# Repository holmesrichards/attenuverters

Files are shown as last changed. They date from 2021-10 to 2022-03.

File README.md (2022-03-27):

# Attenuverters

This is a utility synthesizer module in Kosmo format. It provides three attenuverters — that is, on each of the Out 1/2/3 outputs is whatever voltage went into In 1/2/3 with buffering and attenuation and, if the attenuator slider is below the midpoint, inverted as well. 

A toggle switch allows replacing In 1 with a 10 volt reference, allowing you to get any DC voltage from -10 V to +10 V on Out 1.

The sum of the three outputs appears on the Sum Out jack, and the inverted sum on the inverted Sum Out jack.

The attenuverters' response to the slider position is nonlinear: it is steeper on the ends than in the middle, making it easier to set small values precisely.

The design is inspired and informed by the Kassutronics Attenuverter/Mixer Eurorack module.

## Current draw
11 mA +12 V, 10 mA -12 V

## Photos

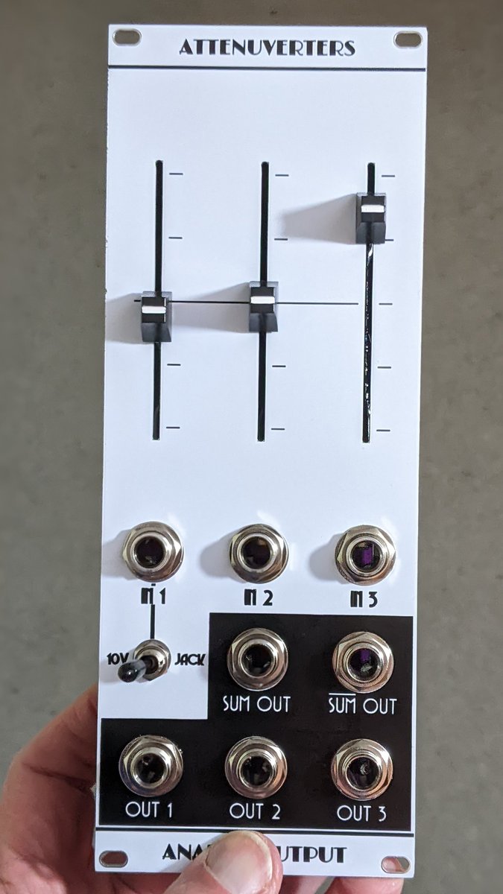
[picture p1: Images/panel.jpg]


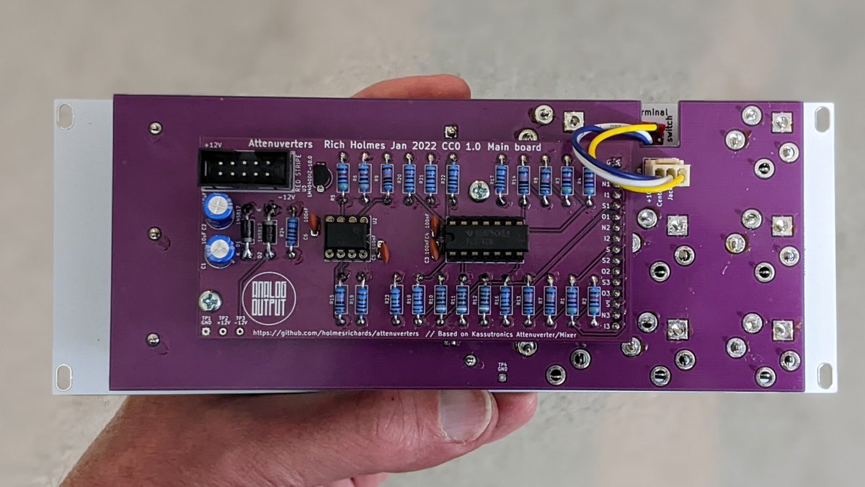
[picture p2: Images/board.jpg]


## Documentation

* [Schematic](Docs/attenuverters.pdf)
* PCB layout: [front](Docs/attenuverters_layout_front.pdf), [back](Docs/attenuverters_layout_back.pdf)
* [BOM](Docs/attenuverters_bom.md)
* [Build notes](Docs/attenuverters_build.md)

## GitHub repository

* [https://github.com/holmesrichards/attenuverters](https://github.com/holmesrichards/attenuverters)

## Submodules

This repo uses submodules aoKicad and Kosmo_panel, which provide needed libaries for KiCad. To clone:

```
git clone git@github.com:holmesrichards/attenuverters.git
git submodule init
git submodule update
```

Alternatively do

```
git clone --recurse-submodules git@github.com:holmesrichards/attenuverters.git
```

Or if you download the repository as a zip file, you must also click on the "aoKicad" and "Kosmo\_panel" links on the GitHub page (they'll have "@ something" after them) and download them as separate zip files which you can unzip into this repo's aoKicad and Kosmo\_panel directories.

If desired, copy the files from aoKicad and Kosmo\_panel to wherever you prefer (your KiCad user library directory, for instance, if you have one). Then in KiCad, go into Edit Symbols and add symbol libraries 

```
aoKicad/ao_symbols
Kosmo_panel/Kosmo
```
and go into Edit Footprints and add footprint libraries 
```
aoKicad/ao_tht
Kosmo_panel/Kosmo_panel.
```

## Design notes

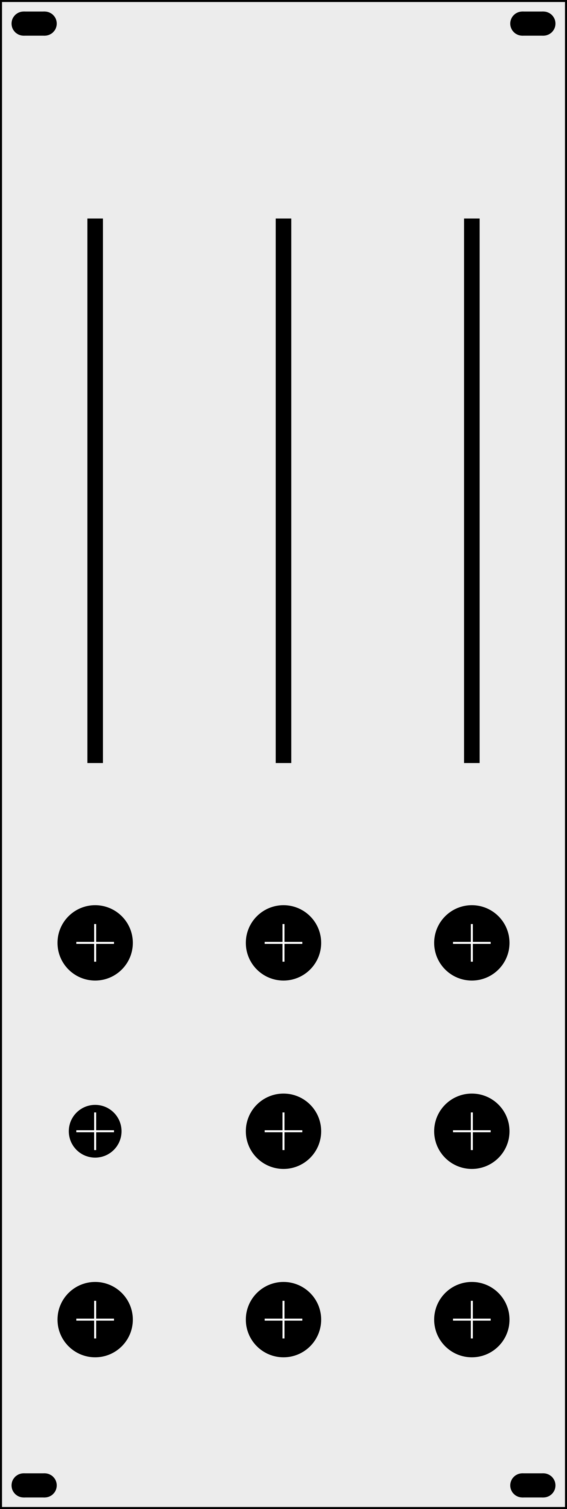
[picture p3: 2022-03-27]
Images/attenuverters_panel_holes.png

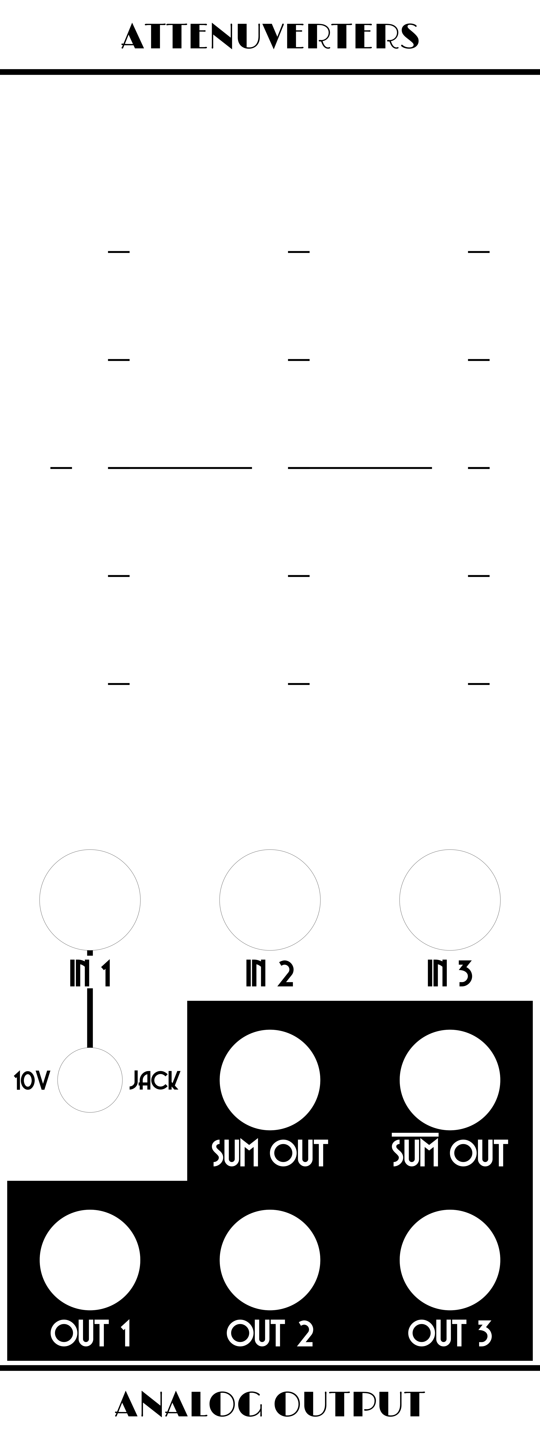
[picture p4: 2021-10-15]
Images/attenuverters_panel_art.png

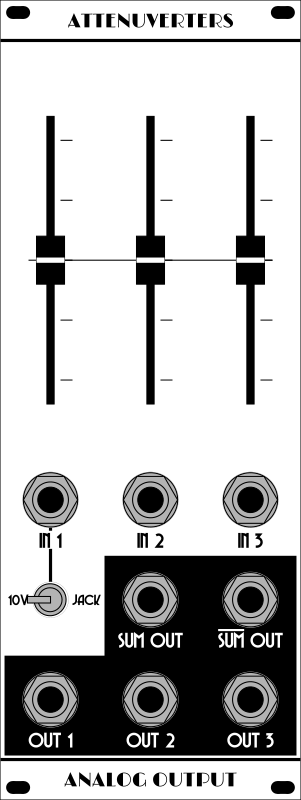
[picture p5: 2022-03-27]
Images/attenuverters_panel.png

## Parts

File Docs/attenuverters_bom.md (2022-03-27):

# attenuverters.kicad_sch BOM

Sat 26 Mar 2022 01:27:37 PM EDT

Generated from schematic by Eeschema 6.0.4-6f826c9f35~116~ubuntu20.04.1

**Component Count:** 53

| Refs | Qty | Component | Description | Vendor | SKU |
| ----- | --- | ---- | --- | ---- | ---- |
| C1, C2 | 2 | 10uF | Electrolytic capacitor | Tayda | A-4349 |
| C3, C4, C5, C6 | 4 | 100nF | Ceramic capacitor | Tayda | A-553 |
| D1, D2 | 2 | 1N5817 | Schottky Barrier Rectifier Diode, DO-41 | Tayda | A-159 |
| J1 | 1 | Conn_01x16 | 1x16 pin header, 2.54 mm |  |  |
| J2 | 1 | Conn_01x16 | 1x16 pin socket, 2.54 mm |  |  |
| J3, J4, J5, J12, J13 | 5 | AudioJack2 | 1/4" Audio Jack, 2 Poles (Mono / TS) | Tayda | A-1121 |
| J6 | 1 | 3_pin_Molex_header | KK254 Molex header | Tayda | A-805 |
| J7 | 1 | Synth_power_2x5 | Shrouded header 2x5 | Tayda | A-2939 |
| J8 | 1 | 3_pin_Molex_connector | KK254 Molex connector | Tayda | A-827 |
| J9, J10, J11 | 3 | AudioJack2_SwitchT | 1/4" Audio Jack, 2 Poles (Mono / TS), Switched T Pole (Normalling) | Tayda | A-1121 |
| R1, R2, R3, R4, R5, R6 | 6 | 47k | Resistor | Tayda |  |
| R7, R8, R9, R13, R14, R15 | 6 | 100k | Resistor | Tayda |  |
| R10, R11, R12 | 3 | 9.1k | Resistor | Tayda |  |
| R16, R17, R18, R22, R23, R24 | 6 | 1k | Resistor | Tayda |  |
| R19, R20, R21 | 3 | 10k | Resistor | Tayda |  |
| RV1, RV2, RV3 | 3 | B100k | Slide potentiometer | Tayda |  |
| SW1 | 1 | SW_SPDT | Switch, single pole double throw | Tayda | A-3186 |
| U1 | 1 | TL074 | Quad operational amplifier, DIP-14 | Tayda | A-1138 |
| U2 | 1 | TL071 | Operational amplifier, DIP-8 | Tayda | A-1135 |
| U3 | 1 | LM4040DIZ-10.0 | 10.0V Precision Micropower Shunt Voltage Reference, TO-92 |  |  |
| | 1 | | 8 pin DIP socket |
| | 1 | | 14 pin DIP socket |

Slider caps, M3 standoffs and screws

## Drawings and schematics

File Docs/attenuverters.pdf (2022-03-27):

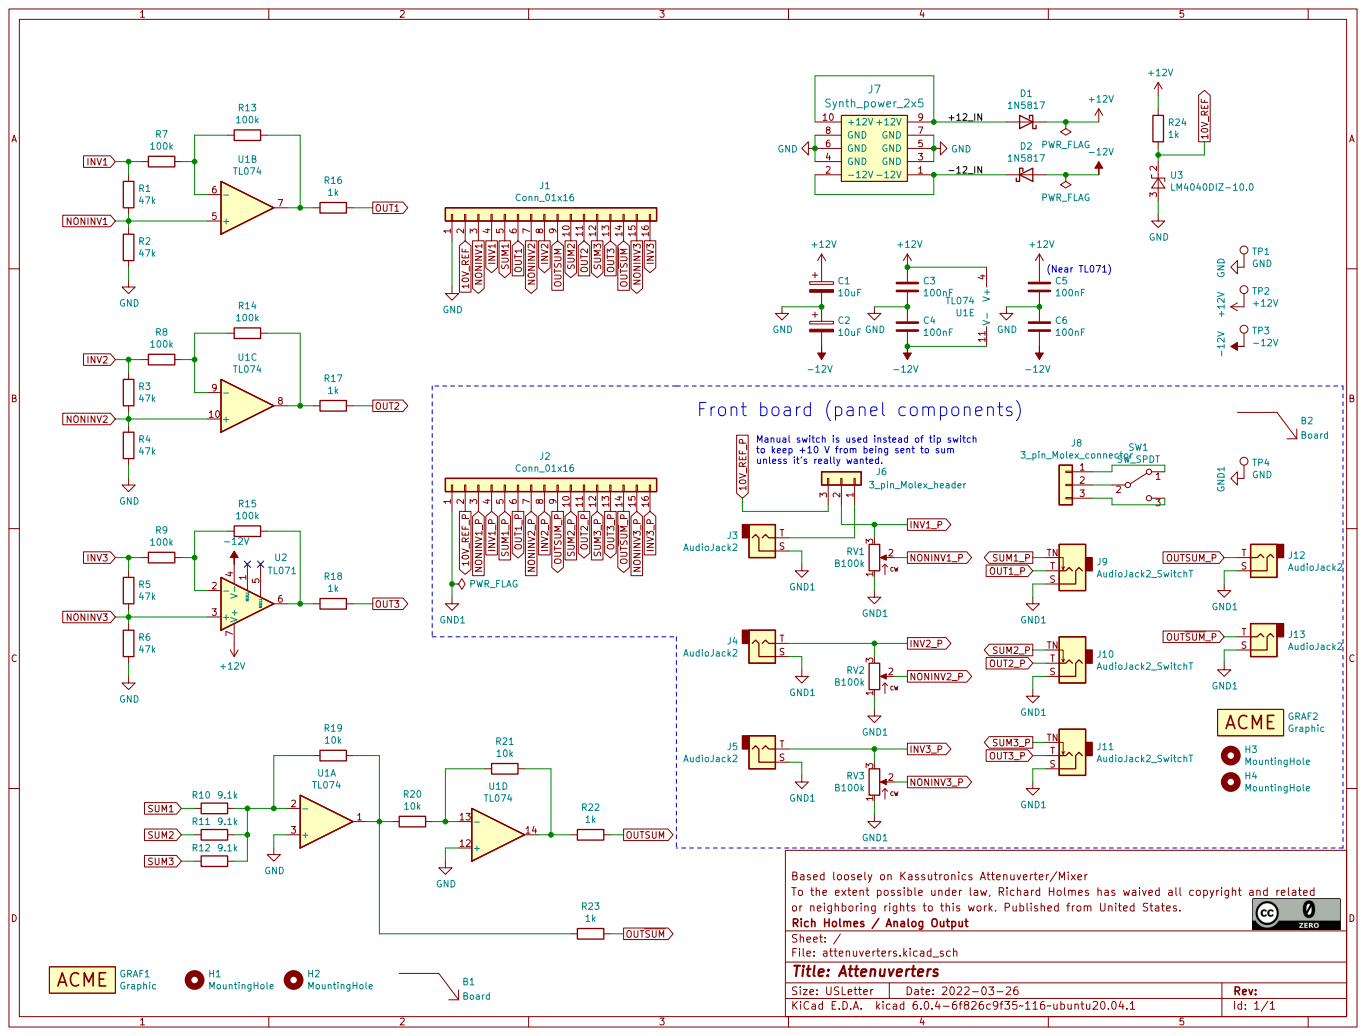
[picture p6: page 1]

-12_IN Front board (panel components)

Manual switch is used instead of tip switch
to keep +10 V from being sent to sum
unless it's really wanted.

Based loosely on Kassutronics Attenuverter/Mixer 1

To the extent possible under law, Richard Holmes has waived all copyright and related
or neighboring rights to this work. Published from United States.
File: attenuverters.kicad_sch Sheet: / Rich Holmes / Analog Output

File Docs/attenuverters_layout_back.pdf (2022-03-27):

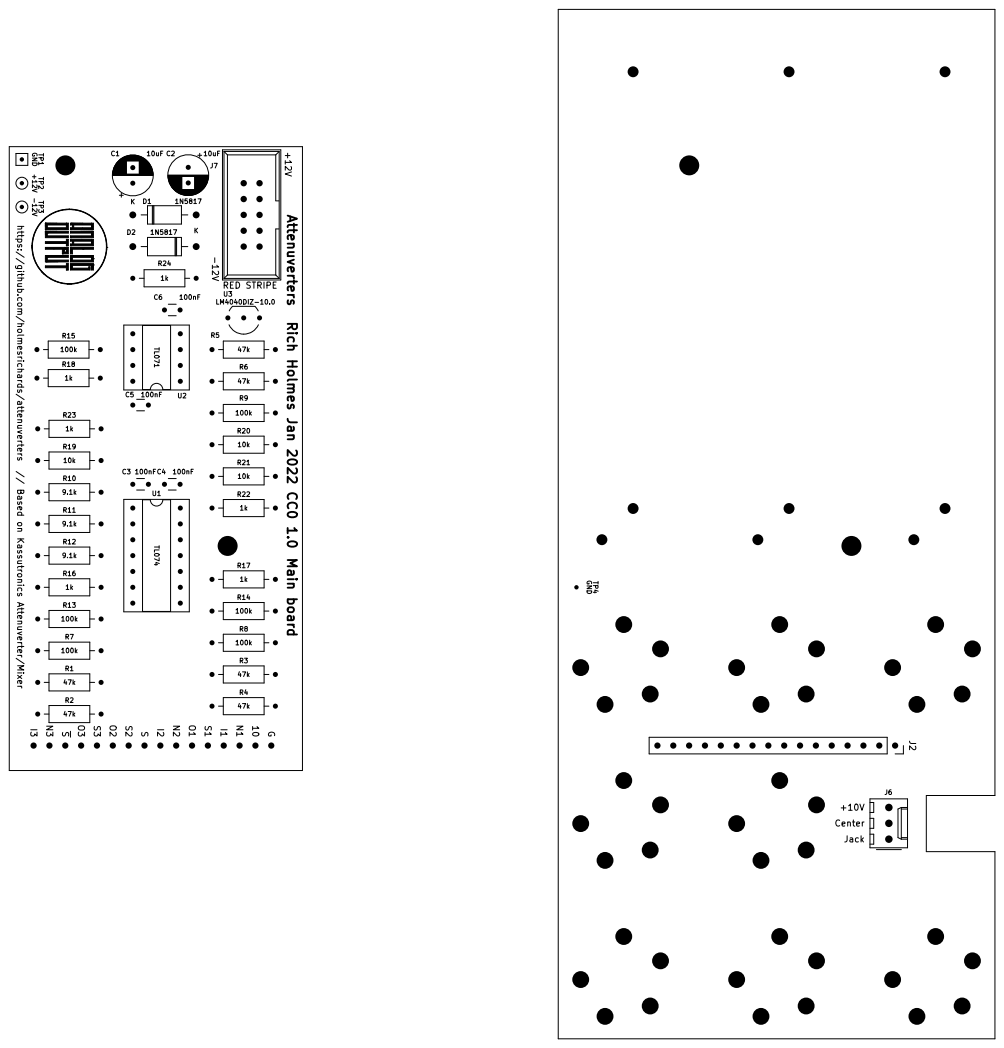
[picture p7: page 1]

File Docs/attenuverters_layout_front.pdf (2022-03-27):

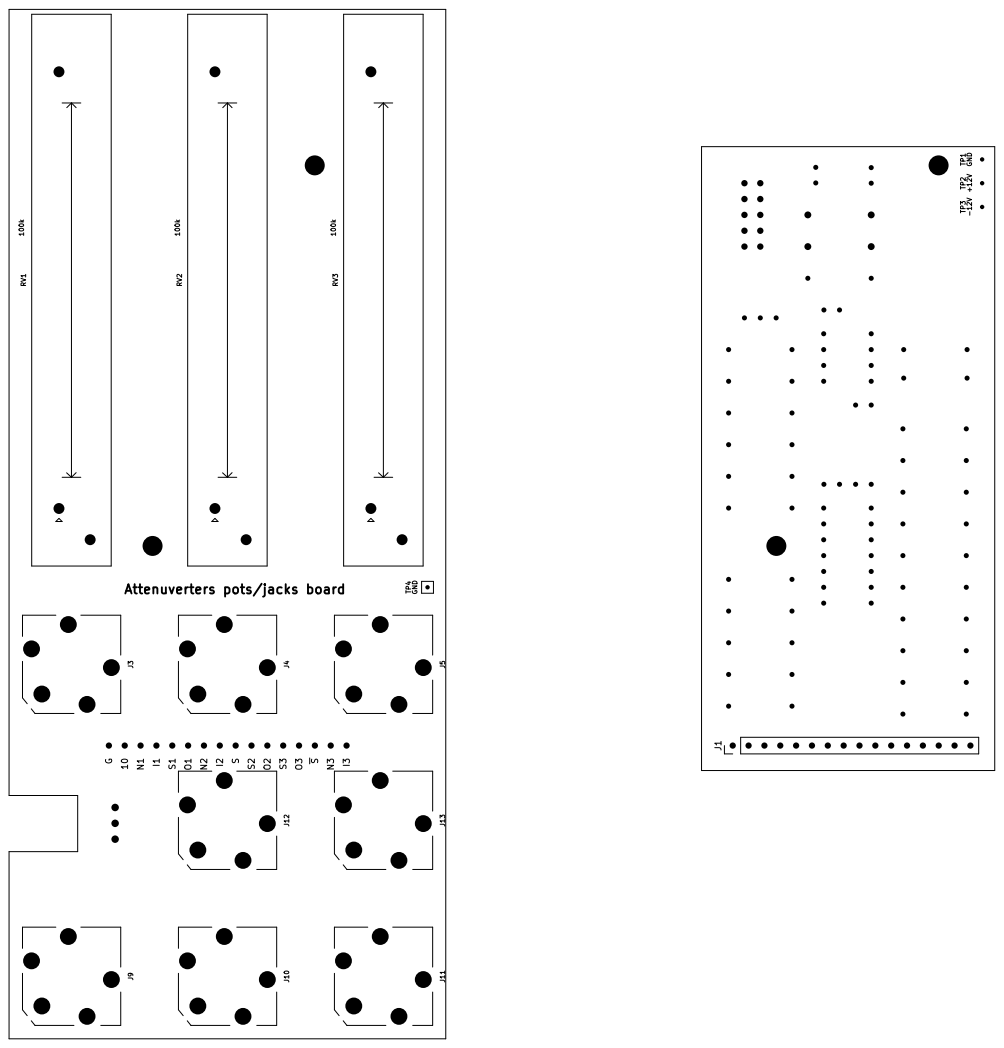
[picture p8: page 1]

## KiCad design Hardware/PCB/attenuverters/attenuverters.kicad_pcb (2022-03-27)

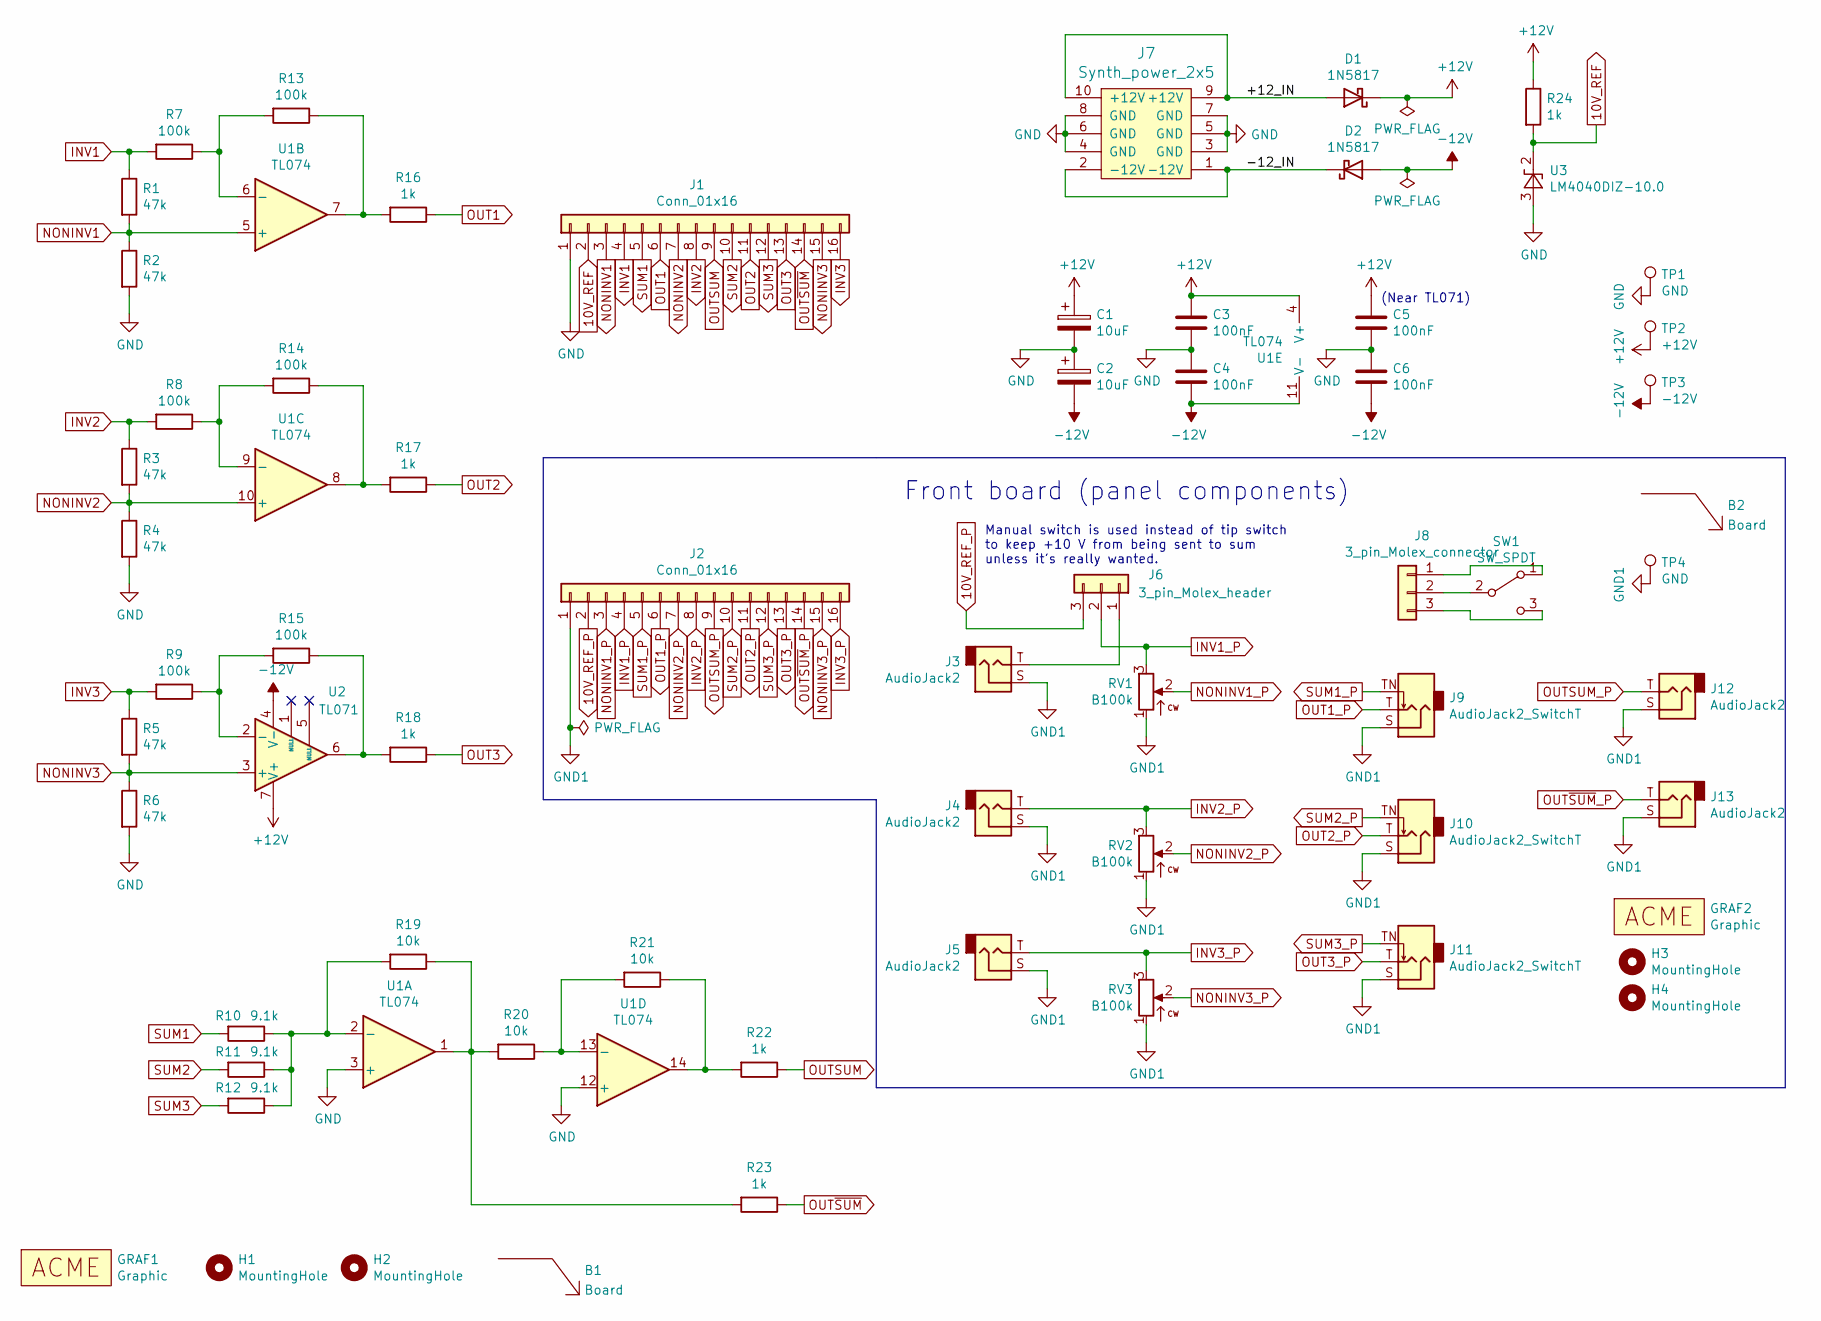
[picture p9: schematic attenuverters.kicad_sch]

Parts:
B1, B2: Board; Board_Marker
C1, C2: 10uF; CP_Radial_D6.3mm_P2.50mm
C3, C4, C5, C6: 100nF; C_Disc_D3.0mm_W1.6mm_P2.50mm
D1, D2: 1N5817; D_DO-41_SOD81_P10.16mm_Horizontal
GRAF1: Graphic; attenuverters_panel_holes
GRAF2: Graphic; analogoutput_12mm
H1, H2, H3, H4: MountingHole; MountingHole_3.2mm_M3
J1: Conn_01x16; PinHeader_1x16_P2.54mm_Vertical
J2: Conn_01x16; PinSocket_1x16_P2.54mm_Vertical
J3, J4, J5, J12, J13: AudioJack2
J6: 3_pin_Molex_header; Molex_KK-254_AE-6410-03A_1x03_P2.54mm_Vertical
J7: Synth_power_2x5; Power_Header
J8: 3_pin_Molex_connector; Molex_KK-254_AE-6410-03A_1x03_P2.54mm_Vertical
J9, J10, J11: AudioJack2_SwitchT
R1, R2, R3, R4, R5, R6: 47k; R_Axial_DIN0207_L6.3mm_D2.5mm_P10.16mm_Horizontal
R7, R8, R9, R13, R14, R15: 100k; R_Axial_DIN0207_L6.3mm_D2.5mm_P10.16mm_Horizontal
R10, R11, R12: 9.1k; R_Axial_DIN0207_L6.3mm_D2.5mm_P10.16mm_Horizontal
R16, R17, R18, R22, R23, R24: 1k; R_Axial_DIN0207_L6.3mm_D2.5mm_P10.16mm_Horizontal
R19, R20, R21: 10k; R_Axial_DIN0207_L6.3mm_D2.5mm_P10.16mm_Horizontal
RV1, RV2, RV3: B100k; Potentiometer_Alpha_RA6020F_Single_Slide
SW1: SW_SPDT; SPDT-toggle-switch-1M-series
TP1, TP4: GND; TestPoint_THTPad_1.5x1.5mm_Drill0.7mm
TP2: +12V; TestPoint_THTPad_D1.5mm_Drill0.7mm
TP3: -12V; TestPoint_THTPad_D1.5mm_Drill0.7mm
U1: TL074; DIP-14_W7.62mm_Socket_LongPads
U2: TL071; DIP-8_W7.62mm_Socket_LongPads
U3: LM4040DIZ-10.0; TO-92_Inline_Wide

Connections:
10V_REF: J1.2, R24.2, U3.2 (K)
10V_REF_P: J2.2, J6.3
+12V: C1.1, C3.1, C5.1, D1.1 (K), R24.1, TP2.1, U1.4 (V+), U2.7 (V+)
-12V: C2.2, C4.2, C6.2, D2.2 (A), TP3.1, U1.11 (V-), U2.4 (V-)
/+12_IN: D1.2 (A), J7.9 (+12V), J7.10 (+12V)
/-12_IN: D2.1 (K), J7.1 (-12V), J7.2 (-12V)
GND: C1.2, C2.1, C3.2, C4.1, C5.2, C6.1, J1.1, J7.3 (GND), J7.4 (GND), J7.5 (GND), J7.6 (GND), J7.7 (GND), J7.8 (GND), R2.2, R4.2, R6.2, TP1.1, U1.3 (+), U1.12 (+), U3.3 (A)
GND1: J2.1, J3.S, J4.S, J5.S, J9.S, J10.S, J11.S, J12.S, J13.S, RV1.1, RV2.1, RV3.1, TP4.1
INV1: J1.4, R1.1, R7.2
INV1_P: J2.4, J6.2, RV1.3
INV2: J1.8, R3.1, R8.2
INV2_P: J2.8, J4.T, RV2.3
INV3: J1.16, R5.1, R9.2
INV3_P: J2.16, J5.T, RV3.3
NONINV1: J1.3, R1.2, R2.1, U1.5 (+)
NONINV1_P: J2.3, RV1.2
NONINV2: J1.7, R3.2, R4.1, U1.10 (+)
NONINV2_P: J2.7, RV2.2
NONINV3: J1.15, R5.2, R6.1, U2.3 (+)
NONINV3_P: J2.15, RV3.2
unnamed: J3.T, J6.1
unnamed: J8.1, SW1.1 (A)
unnamed: J8.2, SW1.2 (B)
unnamed: J8.3, SW1.3 (C)
unnamed: R10.1, R11.1, R12.1, R19.2, U1.2 (-)
unnamed: R13.1, R16.2, U1.7
unnamed: R7.1, R13.2, U1.6 (-)
unnamed: R14.1, R17.2, U1.8
unnamed: R8.1, R14.2, U1.9 (-)
unnamed: R15.1, R18.2, U2.6
unnamed: R9.1, R15.2, U2.2 (-)
unnamed: R19.1, R20.2, R23.2, U1.1
unnamed: R20.1, R21.2, U1.13 (-)
unnamed: R21.1, R22.2, U1.14
OUT1: J1.6, R16.1
OUT1_P: J2.6, J9.T
OUT2: J1.11, R17.1
OUT2_P: J2.11, J10.T
OUT3: J1.13, R18.1
OUT3_P: J2.13, J11.T
OUTSUM: J1.9, R22.1
OUTSUM_P: J2.9, J12.T
OUT~SUM: J1.14, R23.1
OUT~SUM_P: J2.14, J13.T
SUM1: J1.5, R10.2
SUM1_P: J2.5, J9.TN
SUM2: J1.10, R11.2
SUM2_P: J2.10, J10.TN
SUM3: J1.12, R12.2
SUM3_P: J2.12, J11.TN

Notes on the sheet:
(Near TL071)
Manual switch is used instead of tip switch to keep +10 V from being sent to sum unless it's really wanted.
Front board (panel components)

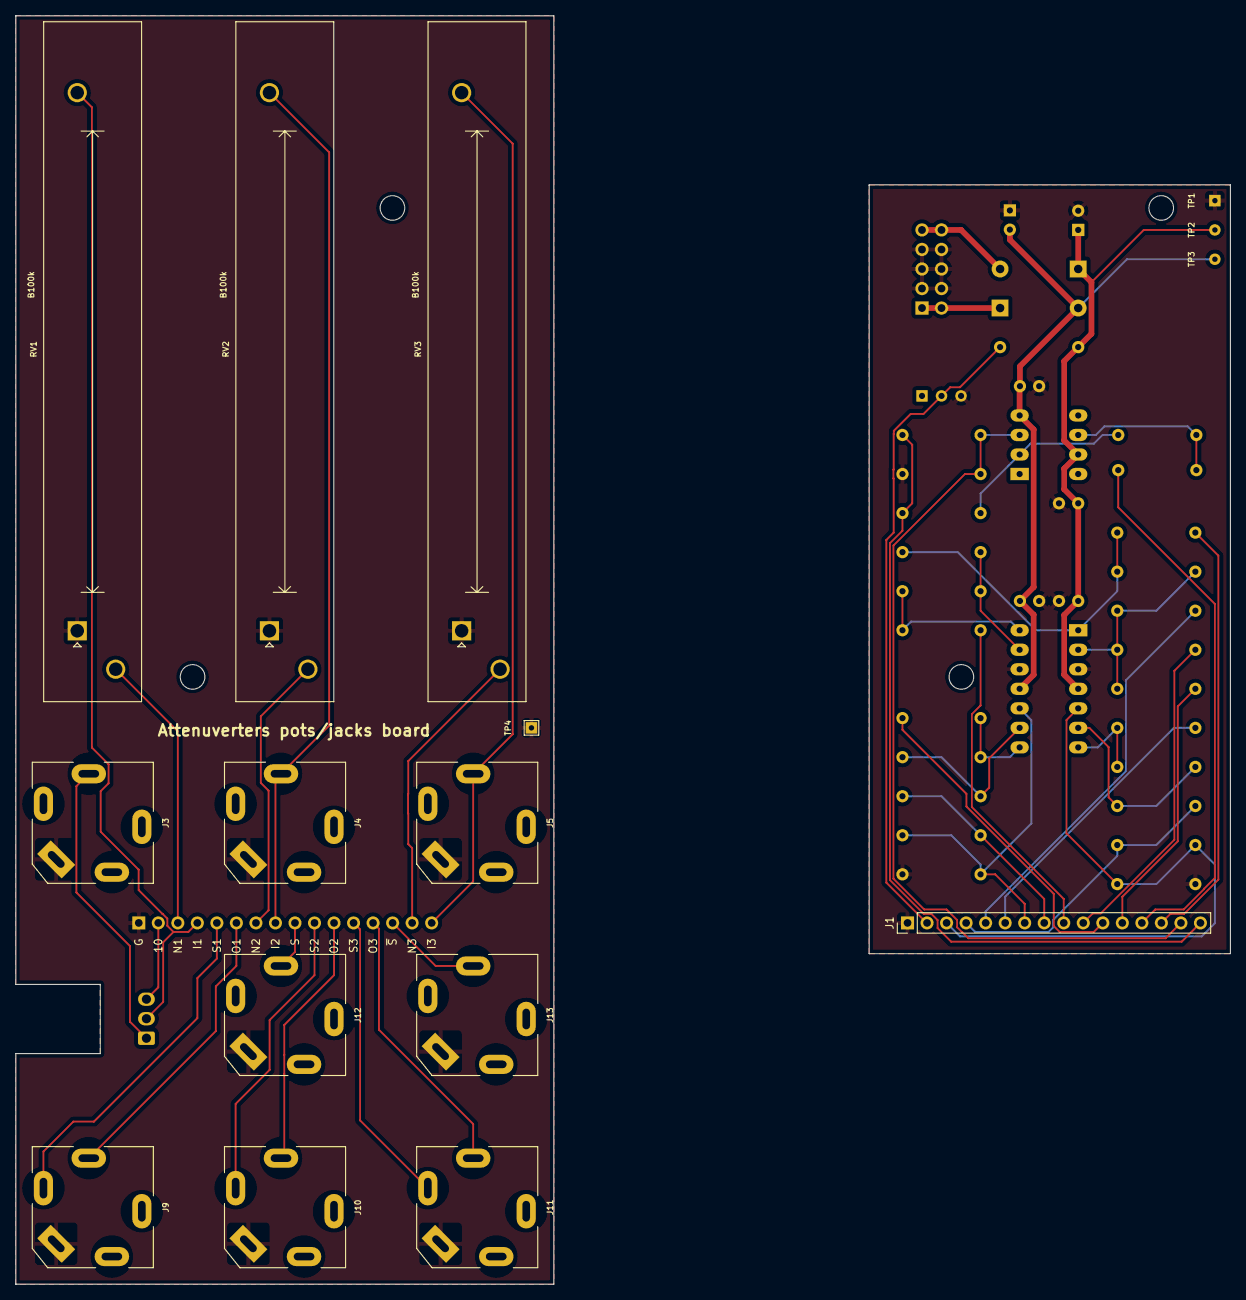
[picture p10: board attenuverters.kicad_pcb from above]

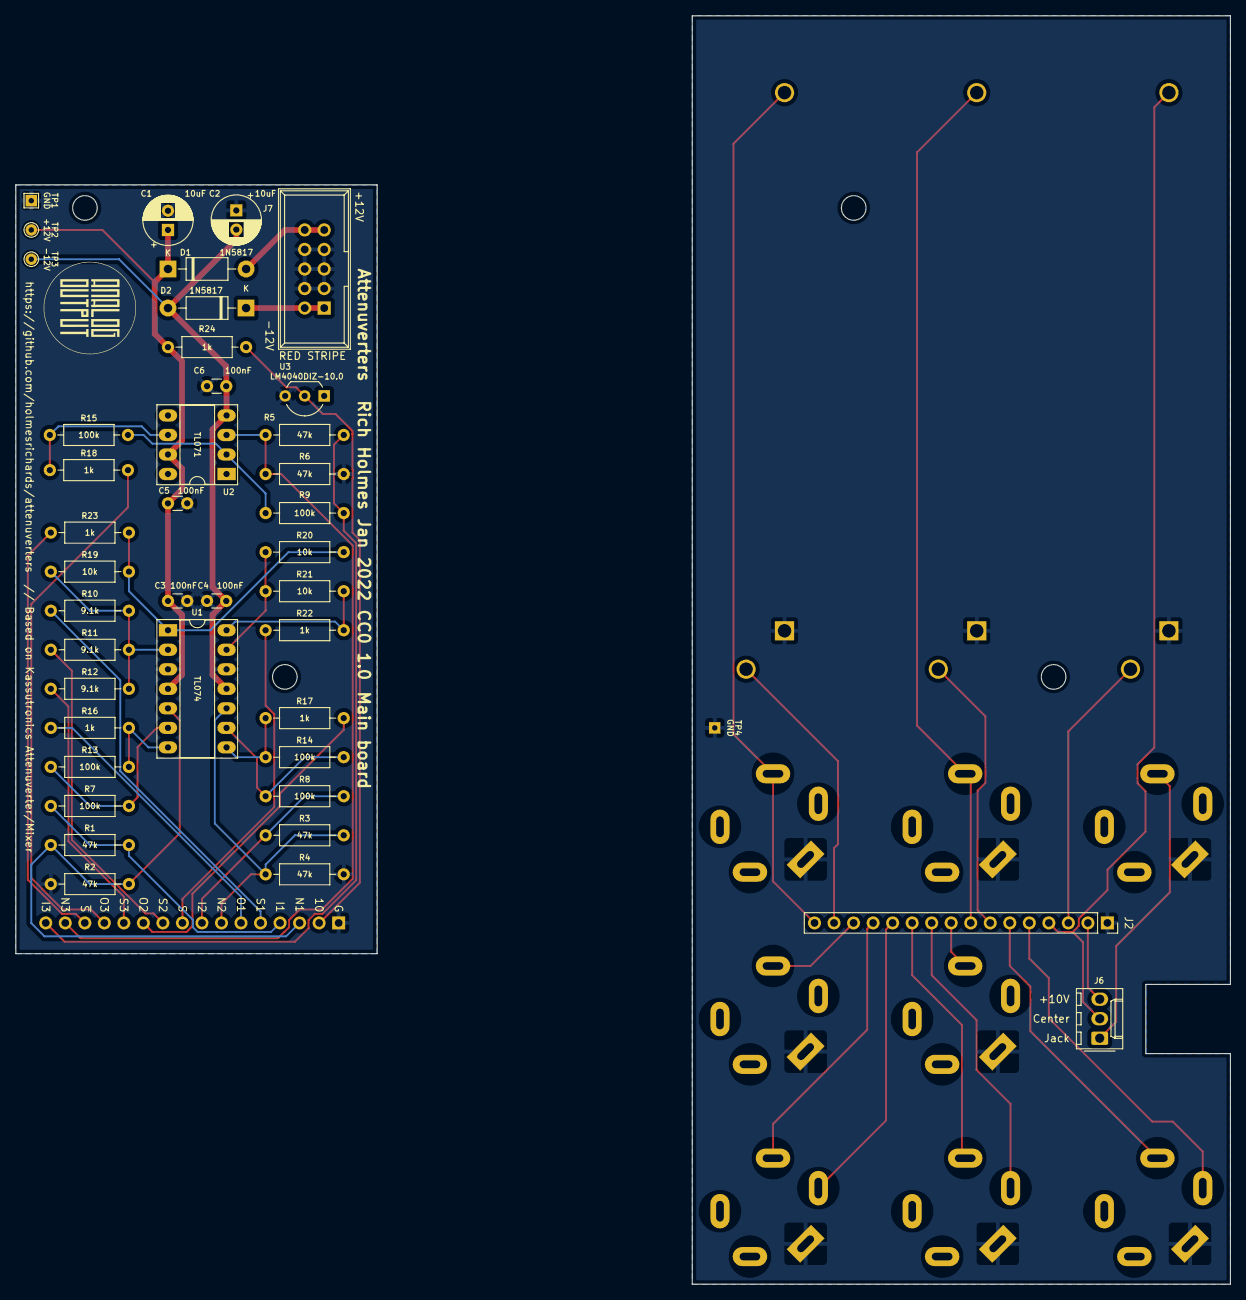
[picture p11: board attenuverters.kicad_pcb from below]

Board: 2 copper layers, 158.0 x 165.0 mm, 62 parts (42 on the bottom side), 47 nets.

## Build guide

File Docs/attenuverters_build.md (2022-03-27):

# Attenuators build notes

There isn't much to say about building this module. As usual, start with the shortest components (resistors, diodes) and finish with the tallest (headers, electrolytic caps). Notice that the pin header/socket and the Molex header will go on the PCB sides opposite the rest of the components.

Before soldering them, put the 16 pin header and socket together and sandwich them between the front and main PCBs. Use screws, washers, and spacers to secure the two boards together. Once they're aligned and held in place, solder the headers. Definitely do this and check it before soldering the jacks, otherwise getting to the pin socket on the front board to solder it will be next to impossible. Then place the sliders and jacks in their places on the front board, put the panel on top of them, and fasten it down with nuts on several of the jacks. Stick pieces of foam or something like that between the sliders and the panel to keep them in place, turn the assembly over, and solder the sliders and jacks to the PCB.

Finally, solder wires to the toggle switch, secure it to the front panel, and then attach a Molex connector to the wires to connect to the Molex header on the back of the front board. Of course you can leave out the Molex and just solder the wires straight to the PCB if you'd rather.

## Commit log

2021-10-15 Initial version
    [attenuverters.kicad_pcb, attenuverters.sch]
2021-10-19 +10V_P symbol in new local library
    [attenuverters.sch]
2021-10-31 k not K; BOM
    [attenuverters.sch]
2021-11-01 Revised PCB
    [attenuverters.kicad_pcb, attenuverters.sch]
2021-11-01 Panel in KiCad
    [attenuverters_panel.kicad_pcb, attenuverters_panel.sch]
2021-11-02 Rear panel labels
    [attenuverters_panel.kicad_pcb]
2021-11-12 2x072->074, correct wrong power connections
    [attenuverters.kicad_pcb, attenuverters.sch]
2021-11-18 Test points
    [attenuverters.kicad_pcb, attenuverters.sch]
2022-02-01 Better .gitignore; KiCad 6 version
    [attenuverters.kicad_pcb, attenuverters.kicad_sch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]
2022-03-27 Catch up to 1st fab run version
    [attenuverters.kicad_pcb, attenuverters.kicad_sch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]
2022-03-27 Slot version of jacks
    [attenuverters.kicad_pcb, attenuverters.kicad_sch]

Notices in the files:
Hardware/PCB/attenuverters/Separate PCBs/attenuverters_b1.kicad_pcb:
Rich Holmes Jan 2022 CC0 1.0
